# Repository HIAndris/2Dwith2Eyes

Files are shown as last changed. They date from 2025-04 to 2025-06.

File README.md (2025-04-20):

# 2D2E – WRO Future Engineers 2025

* **Project Name:** 2D2E
* **Author:** [István András Hegedűs](https://github.com/HIAndris)
* **Contributors:** [Dávid Laczkó](https://github.com/Zsep1), [Csongor Botond Vincze](https://github.com/Slampis1)
* **Mentor:** [István Hegedűs](https://github.com/istvan-hegedus)
* **License:** [Apache 2.0](https://www.apache.org/licenses/LICENSE-2.0)
* **Competition:** [World Robot Olympiad (WRO) – Hungary](https://wro.hu/) – [Future Engineers category, 2025](https://wro.hu/future-engineers-kategoria/)

## 📌 Description

**2D2E** refers to **2 Dimensions with 2 Eyes** and is an open-source educational project developed for the **World Robot Olympiad 2025 – Future Engineers** category.
The name comes from our goal of two 1 dimensional camera feeds that create a 2 dimensional perception.

The goal of the project is to create a system that:

- Uses two camera modules (OV7670)
- Maps a horizontal slice of 3D space in real time
- Effectively simulates **depth perception with two eyes** in a 3D environment

Potential applications include:
- Obstacle detection
- Image processing
- Spatial awareness
- Demonstrations for STEM education

## ⚙️ Technical Overview

- Hardware: ESP32-S3-WROOM-1
- Dual OV7670 camera modules
- Development environment: PlatformIO with CLion
- Programming language: C/C++

## 📦 Project Structure

- `src/` – Main source code
- `include/` – Header files
- `lib/` – Libraries
- `LICENSE` – Apache 2.0 license file
- `README.md` – This file

## 🔓 License

This project is released under the [Apache License 2.0](https://www.apache.org/licenses/LICENSE-2.0).

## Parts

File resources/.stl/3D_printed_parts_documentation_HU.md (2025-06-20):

# 3D nyomtatott alkatrészek
*Minden kinyomtatott prototípus, jelentős változtatás a modellen, illetve végleges, 3D nyomtatott alkatrész itt található.*

### alvaz_elulso.stl
- A modell hátulsó részén az eredeti 8mm vastagság fele mérhető 16mm hosszig, amely a **kettő alváz fél** összefogatását teszi lehetővé hat darab 3mm átmérőjű lyuk segítségével.
- A **"nyak_tarto_bal_2.stl"** és a **"nyak_tarto_jobb_2.stl"** modelleket biztosító 3mm átmérőjű 1-1 lyuk távolsága egymástól, a lyukak középpontjaitól mérve 50mm. Az objektum legközelebbi oldalfalától a lyukak széléig megközelítőleg 10.4mm mérhető.
- A **"kanyarodo_motor_tartokeret_2.stl"** modellt biztosító 3mm átmérőjű kettő lyuk távolsága egymástól, a lyukak középpontjaitól mérve 50mm, Az objektum legközelebbi oldalfalától a lyukak széléig megközelítőleg 7.8mm mérhető, ebben az esetben a kormánymű kerekeinek kivágott tér oldalfalától mérve.
- A kormányműt biztosító 3mm átmérőjű kettő lyuk távolsága egymástól, a lyukak középpontjaitól mérve 32mm, vagy négy **Lego stud**-nyi. Az objektum legközelebbi oldalfalától a lyukak széléig megközelítőleg 12.4mm mérhető.
- A "T" alakú, 2mm mélységű bemélyedés az objektum közepén a kormánymű első verziója miatt lett megszerkesztve, mivel a differenciálmű túllógott a **"Lego Technic Beam Frame 5x7"**-en. A jelenlegi kormánymű verziójában a bemélyedésnek nincsen szerepe.
- Az "M" alakú lyukak az objektum közepén a kormánymű első verziója miatt lett megszerkesztve, ezek engedélyezték a forgató karok, avagy a **"Lego Technic 3L beam"**-ek elfordulását. Egy "M" alakú lyuk kettő ugyanolyan részből áll, kettő lekerekített végű 30 fokos szögből. A jelenlegi kormánymű verziójában a lyukaknak nincsen szerepe.
- A "C" és "Ↄ" (fordított C) alakú lyukak az objektum szélein a kormánymű kerekeinek kihagyott tér, ahol szabadon foroghatnak a kerekek a forgási tengely körül 30 fokban. Eredetileg a kormánymű első verziójához lett tervezve a tér, de mivel a kerekek forgástengelye hasonló az előző verzióhoz, tökéletesen működik a második verzióval is.
- Az 50mm magasságú, 25mm szélességű, megközelítőleg 12.2mm vastagságú kitüremkedés az objektum elején a kettő, **0V7670** nevezetű **kamera** és kettő, **TOF200C-VL53L0X** nevezetű **távolságszenzor** megfogatását biztosítja. A kamerák lyukai 3mm átmérőjűek, a távolságszenzorok lyukai 2mm átmérőjűek. A **0V7670** kamerák lyukainak távolsága egymástól, a lyukak középpontjaitól mérve 15mm, az objektum legközelebbi oldalfalától a lyukak széléig megközelítőleg 4.2mm mérhető. A **TOF200C-VL53L0X** **távolságszenzorok** lyukainak távolsága egymástól, a lyukak középpontjaitól mérve 14.4mm, az objektum legközelebbi oldalfalától a lyukak széléig megközelítőleg 3.8mm mérhető.
- A 6mm hosszúságú kitüremkedés az objektum orrán egy **TOF200C-VL53L0X távolságszenzor** megfogatását biztosítja. A távolságszenzor 2mm átmérőjű lyukainak távolsága egymástól, a lyukak középpontjaitól mérve 14.4mm, az objektum legközelebbi oldalfalától a lyukak széléig 3mm mérhető. A csavar anyáknak kihagyott lyukak 3x7mm-esek. Az anyák lyukain túl vannak 2mm átmérőjű, 1.6mm mélységű bemélyedések a csavaroknak hagyva az **erős megfogatás érdekében**.

### alvaz_hatso.stl
- A modell elülső részén az eredeti 8mm vastagság fele észlelhető 16mm hosszig, amely a **kettő alváz fél** összefogatását teszi lehetővé hat darab 3mm átmérőjű lyuk segítségével.
- A **"hajtomotor_tartokeret_4.stl"** modellt biztosító négy lyuk, a 2-2 egymástól messzebb lévő 3mm átmérőjű lyukak távolsága egymástól, középpontjuktól mérve 51mm, a 2-2 egymáshoz közelebb lévő 3mm átmérőjű lyukak távolsága egymástól, középpontjuktól mérve megközelítőleg 9.9mm.
- A kettő **"elemtarto_5.stl"** modelleket biztosító 2-2 lyuk, a 2-2 egymástól messzebb lévő 3mm átmérőjű lyukak távolsága egymástól, középpontjuktól mérve megközelítőleg 51.4mm, a 2-2 egymáshoz közelebb lévő 3mm átmérőjű lyukak távolsága egymástól, középpontjuktól mérve 29 fokban egymáshoz, megközelítőleg 18.8mm. Az objektum legközelebbi oldalfalától a legszélsőbb kettő lyuk széléig megközelítőleg 9.9mm mérhető.
- A hajtóművet biztosító négy lyuk, a 2-2 egymástól messzebb lévő 3mm átmérőjű lyukak távolsága egymástól, középpontjuktól mérve 48mm, vagy hat **Lego stud**-nyi, a 2-2 egymáshoz közelebb lévő 3mm átmérőjű lyukak távolsága egymástól, középpontjuktól mérve megközelítőleg 31.6mm, vagy közel négy **Lego stud**-nyi. Az objektum legközelebbi oldalfalától a legszélsőbb kettő lyuk széléig megközelítőleg 6.4mm mérhető.
- A lekerekített téglalap alapú 35x15mm-es lyuk az objektum közepén a, **17HS3430** nevezetű hajtómotor által megforgatott **nagyobb fogaskerék** elférése érdekében kihagyott tér volt, mielőtt ezt a fogaskereket lecseréltük volna egy ugyanolyan méretűre, mint amely a hajtóművön is található, a túlzott nyomaték miatt. 
- A lekerekített téglalap alapú, megközelítőleg 32.3x27.6mm-es lyuk az objektum végénél a **"Lego Technic Beam Frame 5x7"**-en túllógó differenciálmű elférése érdekében kihagyott tér.

### alvaz_hatso_2.stl
- A lekerekített négyzet alapú 24x24 mm-es lyuk az objektum közepén az újranyomtatásból eredő **kevesebb filamentfelhasználás** érdekében kihagyott tér.
- A lekerekített paralelogramma alapú, megközelítőleg 34.1x18.4-mm-es lyuk az objektum közepén az újranyomtatásból eredő **kevesebb filamentfelhasználás** érdekében kihagyott tér.
- Az objektum hátulsó lekerekített szélei az újranyomtatásból eredő **kevesebb filamentfelhasználás** érdekében kihagyott tér.
- A **hajtóművet** biztosító négy lyuk és a differenciálmű elférése érdekében kihagyott lyuk meg lett hosszabbítva 5mm-rel a robot menetirányával megegyező irányába, annak érdekében, hogy a hajtőművet be lehessen oly módon pozicionálni, hogy a **fogas szíj** szorosan érintkezzen a **fogaskerekekkel**.

### elemtarto.stl
- A modell nem saját tervezésű, **pixelle alkotó eredeti modellje**
- Forrás: https://www.thingiverse.com/thing:2339441
- Licenc: Creative Commons Attribution–NonCommercial (CC-BY)

### elemtarto_2.stl
- Az elölnézetből a bal oldalon lévő, 18.3mm hosszúágú, 11mm szélességű, megközelítőleg 13.33mm vastagságú, a jobb oldalon lévő, megközelítőleg 1.57mm hosszúágú, 11mm szélességű, megközelítőleg 13.33mm vastagságú, **összefogató karokból** kitüremkedő, megközelítőleg 11.85mm hosszúságú, megközelítőleg 7.57mm szélességű, megközelítőleg 3.66mm vastagságú **kitüremkedés/kitüremkedések** az objektum két oldalán a két kinyomtatott elem biztos összefogatása érdekében lettek megszerkesztve. A kitüremkedéseken a kettő 3mm átmérőjű lyukak távolsága egymástól, a lyukak középpontjaitól mérve megközelítőleg 5.92mm. Az objektum legközelebbi oldalfalától a lyukak széléig megközelítőleg 1.46mm mérhető.
- Az objektum alján az **"alvaz_hatso_2.stl"** modellhez biztosító, megközelítőleg 8.27mm hosszúágú, megközelítőleg 8.8mm szélességű, 5mm vastagságú **fogató talpak** találhatók, melyeken 1-1 3mm átmérőjű lyukak vannak. Az objektum legközelebbi oldalfalától a lyukak széléig megközelítőleg 0.8mm mérhető. A nyomtatás utáni talpak letörésének megelőzése érdekében 4mm vastagságú **merevítő bordák** lettek szerkesztve a talpakhoz. 

### elemtarto_3.stl
- Az objektum összes legalsó arca meg lett hosszabbítva 5mm-rel, amely **kettő különálló szegmensre** osztható: egy 3mm-es hosszabbításra és egy 2mm-es hosszabbításra. A 3mm-es hosszabbításnál, az objektum alsó **elemfoglalat**ainak kihagyott lyukakinál, egy 5x3mm téglalap alapú lyuk lett szerkesztve, hogy a két ellenkező tájolású elemet sorosan össze lehessen kötni, és ezáltal elérni, hogy a 2-2 elem az objektum tetejéről adja le az áramot. A 2mm-es hosszabbítás talajt biztosít az objektumnak, a hosszabbítás nélkül a soros kötést létesítő rézköteg lenne a **"alvaz_hatso_2.stl"** objektumhoz erősítve, ami nem ideális.
- Az objektum legközelebbi oldalfalától a **fogató talpak** lyukainak széléig mért új érték megközelítőleg 2.8mm. A **merevítő bordák új vastagsága** megközelítőleg 6.52mm. A bordák és talpak közé lekerekített szél lett szerkesztve nyomtatás utáni letörések megelőzése érdekében. 

### elemtarto_4.stl
- Az objektum oldalain lévő **összefogató karok** el lettek távolítva, mert a nyomtatott **prototípuson letörtek**, nem teljesítettek célnak megfelelően, illetve nem volt rájuk szükség, hiszen a **fogató talpak** elégségesen szorosan tudták megtartani a kinyomtatott prototípust. Helyettük a **merevítő bordák tövei** lettek a modell tetejének szintjéhez tolva, így a talpak biztosabban tudják megtartani az objektumot.
- Az objektum oldalfalain elhelyezkedő 3x2.5mm téglalap alapú fölösleges lyukak **be lettek tömve**.

### elemtarto_5.stl
- Az elemek réseinek hátoldalain egy megközelítőleg 39.46x12.58mm lekerekített téglalap alapú lyuk lett szerkesztve, amely az elemek **hozzáférhetőségét segíti**.

### hajtomotor_tartokeret.stl
- Az 41mm magasságú, 41mm szélességű, 8mm vastagságú objektumban minden szempontból középen eltájolt megközelítőleg 21.87 magasságú, megközelítőleg 21.87mm szélességű, négyzet alapú lyuk lett szekresztve a **17HS3430** nevezetű **hajtómotor hajtótengelye**, és a rá kerülő **fogaskerék** érdekében.
- A **17HS3430 hajtómotort** biztosító 3mm átmérőjű 4 lyuk távolsága egymástól, 2 egymás mellet lévő lyukak középpontjaitól mérve 30mm. Az objektum legközelebbi oldalfalától a lyukak széléig megközelítőleg 3mm mérhető.

### hajtomotor_tartokeret_2.stl
- Az objektumon lévő, minden szempontból középen eltájolt négyzet alapú lyuk új magasság és szélesség értéke megközelítőleg 22.2mm-re változott. A négyzet alapú lyuk közepébe egy megközelítőleg 27.89mm átmérőjű lyuk került kivágásra a **nagyobb fogaskerék** elférése érdekében, mielőtt ezt a fogaskereket **lecseréltük** volna egy ugyanolyan méretűre, mint amely a hajtóművön is található, a **túlzott nyomaték miatt**. 
- Az objektum bal és jobb oldalán, megközelítőleg 5.77mm távolságra lévő, megközelítőleg 24.83mm hosszúágú, megközelítőleg 11.53mm szélességű, 3mm vastagságú **fogató talpak** lettek szerkesztve, amelyek 8mm szélességű, megközelítőleg 4.48mm vastagságú **fogas bordákkal** csatlakoznak a főobjektumhoz 27 fokban. A talpakon 4mm átmérőjű lyukak lettek megszerkesztve. Az objektum legközelebbi oldalfalától a lyukak széléig megközelítőleg 3.76mm mérhető.

### hajtomotor_tartokeret_3.stl
- Az objektum bal és jobb oldalán lévő, megközelítőleg 31.83mm hosszúágú, 8mm szélességű, 5mm vastagságú **fogató talpak** egybe lettek szerkesztve a főobjektummal és közelebb lettek tolva a főobjektumhoz 9.27mm-rel. A **merevítő bordák** tövei feljebb lettek tolva a modell tetejének szintjéhez, amiből adódóan a talpakkal bezárt beesési szögei 13 fokra csökkentek, ami **megfogatási szempontból** gyengébb mint az előző verzióban, de **helytakarékossági szempontból** figyelve optimális.
- A új **fogató talpakon** megszerkesztett 3mm átmérőjű 2-2 lyuk távolsága egymástól, a lyukak középpontjaitól mérve megközelítőleg 9.9mm. Az objektum legközelebbi oldalfalától a lyukak széléig megközelítőleg 2.5mm mérhető. A bordák és talpak közé lekerekített szél lett szerkesztve **nyomtatás utáni letörések** megelőzése érdekében. 
- Az **L298N nevezetű hajtómotor vezérlő** az objektum és a hajtómotor tetején került elhejezésre. A 3mm átmérőjű lyukak az objektum tetején az L298N hajtómotor vezérlő megfogatását biztosítják. A lyukak távolsága egymástól, a lyukak középpontjaitól mérve 37mm, az objektum legközelebbi oldalfalától a lyukak széléig 1.5mm mérhető. A csavar anyáknak kihagyott lyukak 4x7mm-esek. Az anyák lyukain túl vannak 3mm átmérőjű, 1.6mm mélységű bemélyedések a csavaroknak hagyva, az **erős megfogatás érdekében**.

### hajtotengely_axle_atalakito.stl
- A 13mm hosszúságú, 10mm szélességű, 10mm magasságú, lekerekített téglatest alapú objektum egyik oldalán egy 5mm bemélyedésű **28BYJ-48 nevezetű kanyarodó motor hajtótengely** alapú lyuk, másik oldalán egy 5mm bemélyedésű **Lego Axle** alapú lyuk.

### hajtotengely_axle_atalakito_2.stl
- Az 5mm bemélyedésű **28BYJ-48 kanyarodó motor kayarodótengely** alapú lyuk mélysége 6mm-ré, az 5mm bemélyedésű **Lego Axle** alapú lyuk mélysége pedig 8mm-ré változott.
- A két lyuk között egy 2mm átmérőjű lyuk lett kivágva, a kinyomtatás utáni **egyszerű filament eltávolítás** érdekében.
- A **Lego Axle** alapú lyuk oldali része az objektumnak henger formává lett lekerekítve.

### kanyarodo_motor_tartokeret.stl
- A megközelítőleg 24.46mm magasságú, 42mm szélességű, 7mm vastagságú főobjektumban, a szélességi tengely szempontjából középen eltájolt 11 magasságú, 11mm szélességű, négyzet alapú lyuk lett szekresztve, ami közepébe egy 13.5mm átmérőjű lyuk került kivágásra a **kanyarodó motor kanyarodótengelye**, és a **"hajtotengely_axle_atalakito_2.stl"** objektum elférése érdekében.
- A **28BYJ-48 nevezetű kanyarodó motort** biztosító 3mm átmérőjű kettő lyuk távolsága egymástól, a lyukak középpontjaitól mérve 35mm. Az objektum legközelebbi oldalfalától a lyukak széléig megközelítőleg 3.65mm mérhető.
- Az főobjektum bal és jobb oldalán, 8mm távolságra lévő, 17mm hosszúágú, 8mm szélességű, 5mm vastagságú **fogató talpak** lettek szerkesztve, amelyek 7mm vastagságú **fogas bordákkal** csatlakoznak a főobjektumhoz 22 fokban. A talpakon 1-1 3mm átmérőjű lyukak lettek megszerkesztve. Az objektum legközelebbi oldalfalától a lyukak széléig megközelítőleg 2.65mm mérhető. A bordák és talpak közé lekerekített szél lett szerkesztve **nyomtatás utáni letörések** megelőzése érdekében. 

### kanyarodo_motor_tartokeret_2.stl
- Az objektum legfelső arca meg lett hosszabbítva 34mm-rel, az **SBT0811 nevezetű kanyarodó motor vezérlő** megfogatása érdekében. A hosszabbításból adódóan a **merevítő bordák tövei** feljebb lettek tolva a modell tetejének szintjéhez, amiből adódóan a fogató talpakkal bezárt beesés szögei 8.5 fokra csökkentek, ami **megfogatási szempontból** gyengébb mint az előző verzióban, de **helytakarékossági szempontból** figyelve optimális.
- Az **SBT0811 kanyarodó motor vezérlőt** biztosító, 3mm átmérőjű 4 lyuk távolsága egymástól, a 2-2 egymástól messzebb lévő lyukak távolsága egymástól, középpontjuktól mérve megközelítőleg 30mm, a 2-2 egymáshoz közelebb lévő lyukak távolsága egymástól, középpontjuktól mérve 25mm. Az objektum legközelebbi oldalfalától a kettő felső lyuk széléig megközelítőleg 3mm mérhető.

### kapcsolo_doboz.stl
- A 18mm hosszúságú, 24mm szélességű, 20mm vastagságú objektumban megszerkesztett 13.05mm hosszúságú, 19.3mm szélességű, téglalap alapú lyuk, a robot be és kikapcsoló **gombjának megfogását** szolgálja.

### kapcsolo_doboz_2.stl
- Az objektum éles szélei **le lettek kerekítve**.

### kormanymu_fogaslec.stl
- Az 57mm hosszúságú, 13mm szélességű, megközelítőleg 7.44mm vastagságú, lekerekített téglatest alakú  objektum, a **"Lego Technic Gear Rack 1x4"** nevezetű elemről lett imitálva. Ez az elem teszi lehetővé a **kormánymű** fordulékonyságát. 
- Az objektumon megszerkesztett **Lego Axle** alapú lyukak távolsága egymástól, a lyukak középpontjaitól mérve 49mm. Az objektum legközelebbi oldalfalától a lyukak széléig megközelítőleg 1.57mm mérhető.

### kormanymu_fogaslec_2.stl
- Az objektum hosszúsága 89mm-re változott, illetve a **"Lego Technic Gear Rack 1x4"**-es rész meghosszabbodott.
- A *Lego Axle* lyukak területén az objektum vastagsága le lett csökkentve megközelítőleg 3.44mm-re, a **"Lego Technic Teeth Gear 20 ooth double bevel"**-re való **szoros kapcsolat érdekében**.

### kormanytengely.stl
- A 71mm hosszúságú, 7mm szélességű, 7mm vastagságú, lekerekített téglatest alakú objektum tette lehetővé az első **kormánymű** fordulékonyságát. Az objektum közepén található elliptikus henger, a **Lego Axle** lyuk érdekében lett megszerkesztve, amely egy **biztos falat ad** a lyuknak az **eltörés megakadályozása** érdekében. Az objektum legközelebbi oldalfalától a lyuk széléig megközelítőleg 4.32mm mérhető.

### nyak_tarto_bal.stl
- Az 50mm hosszúságú, 10mm szélességű, 8mm vastagságú téglalap alapú téglatest főobjektumhoz kapcsolódó, 10mm távolságra lévő, a főobjektummal 11 fokos szöget bezáró meredek **fogas borda**, valamint az ezekből lefelé, a modell tetejének szintjétől mért, 8mm vastagságú, 15mm hosszúságú trapéz alapú **kitüremkedés** a későbbi verzióban a **nyák** és a **„nyak_vaz.stl”** elemek rögzítését szolgálta.

### nyak_tarto_bal_2.stl
- Az objektum a **"nyak_tarto_bal.stl"** objektum lekerekített, illetve fogató lyukakkal felszerelt verziója.
- Az **"alvaz_elulso.stl"** modellre való megfogatást, egy 3mm átmérőjű lyuk teszi lehetővé. Az objektum legközelebbi oldalfalától a lyuk széléig 2.5mm mérhető. A csavar anyáknak kihagyott lyuk 3x7mm-es. Az anya lyukán túl van egy 3mm átmérőjű, 1.6mm mélységű bemélyedés a csavarnak hagyva, az **erős megfogatás érdekében**.
- A **„nyak_vaz_2.stl”** modellt, illetve az azon elhelyezkedő **nyák** megfogatását egy 2mm átmérőjű lyuk teszi lehetővé. Az objektum legközelebbi oldalfalától a lyuk széléig 3mm mérhető.

### nyak_tarto_bal_3.stl
- Az 70mm hosszúságú, 9mm szélességű, 8mm vastagságú, a szélességi tengely szempontjából, a merőlegessel bezárt 98 fokos oldalfalú, a vastagsági tengely szempontjából, a merőlegessel bezárt 84 fokos oldalfalú paralelogramma alapú hasáb főobjektumhoz kapcsolódó, 11mm távolságra lévő, a főobjektummal 8.5 fokos szöget bezáró **meredek fogas borda**, valamint az ezekből lefelé, a modell tetejének szintjétől mért, megközelítőleg 10.49mm vastagságú, megközelítőleg 21.2m hosszúságú, az objektummal bezárt 54 fokos trapéz alapú **kitüremkedés** a későbbi verzióban a nyák és a **„nyak_vaz_2.stl”** elemek rögzítését szolgálta.

### nyak_tarto_bal_4.stl
- Az objektum a **"nyak_tarto_bal_3.stl"** objektum lekerekített, illetve fogató lyukakkal felszerelt verziója.
- Az **"alvaz_elulso.stl"** modellre való megfogatást, egy 3mm átmérőjű lyuk teszi lehetővé. Az objektum legközelebbi oldalfalától a lyuk széléig 2.5mm mérhető. A csavar anyának kihagyott lyuk 3x7mm-es. Az anya lyukán túl van egy 3mm átmérőjű, 1.6mm mélységű bemélyedés a csavarnak hagyva, az **erős megfogatás érdekében**.
- A **„nyak_vaz_2.stl”** modellt, illetve az azon elhelyezkedő **nyák** megfogatását egy 2mm átmérőjű lyuk teszi lehetővé.  Az objektum legközelebbi oldalfalától a lyuk széléig megközelítőleg 3.4mm mérhető.

### nyak_tarto_jobb.stl
- A **"nyak_tarto_bal.stl"** modell tengelyesen tükrözött hasonmása.

### nyak_tarto_jobb_2.stl
- A **"nyak_tarto_bal_2.stl"** modell tengelyesen tükrözött hasonmása.

### nyak_tarto_jobb_3.stl
- A **"nyak_tarto_bal_3.stl"** modell tengelyesen tükrözött hasonmása.

### nyak_tarto_jobb_4.stl
- A **"nyak_tarto_bal_4.stl"** modell tengelyesen tükrözött hasonmása.

### nyak_vaz.stl
- A 87mm hosszúságú, 67mm szélességű, 3mm vastagságú, téglatest alakú objektumban megszerkesztett megközelítőleg 83.38mm hosszúságú, 62mm szélességű, minden szempontból középen eltájolt téglalap alapú lyuk lett szerkesztve. Az objektum belső, rövidebb oldalfalaiból kitüremkedő 6mm hosszúságú, 2mm vastagságú, **tartó felszínek a nyák megtartásáért felelnek**. A tartó felszíneken megszerkesztett, 2mm átmérőjű négy lyuk, 2-2 lyuk távolsága egymástól, a lyukak középpontjaitól mérve 56mm, Az objektum legközelebbi oldalfalától a lyukak széléig megközelítőleg 2mm mérhető.
- A megközelítőleg 11.42mm hosszúságú, megközelítőleg 9.24mm szélességű, **lekerekített kitüremkedés** az objektum oldalán, az **"alvaz_elulso.stl"** modellen megszerkesztett 50mm hosszúságú **kitüremkedésre** volt lefektetve, **az objektum és a nyák biztos megtartása érdekében**.

### nyak_vaz_2.stl
- A lekerekített kitüremkedés az objektum **oldaláról le lett szedve**.

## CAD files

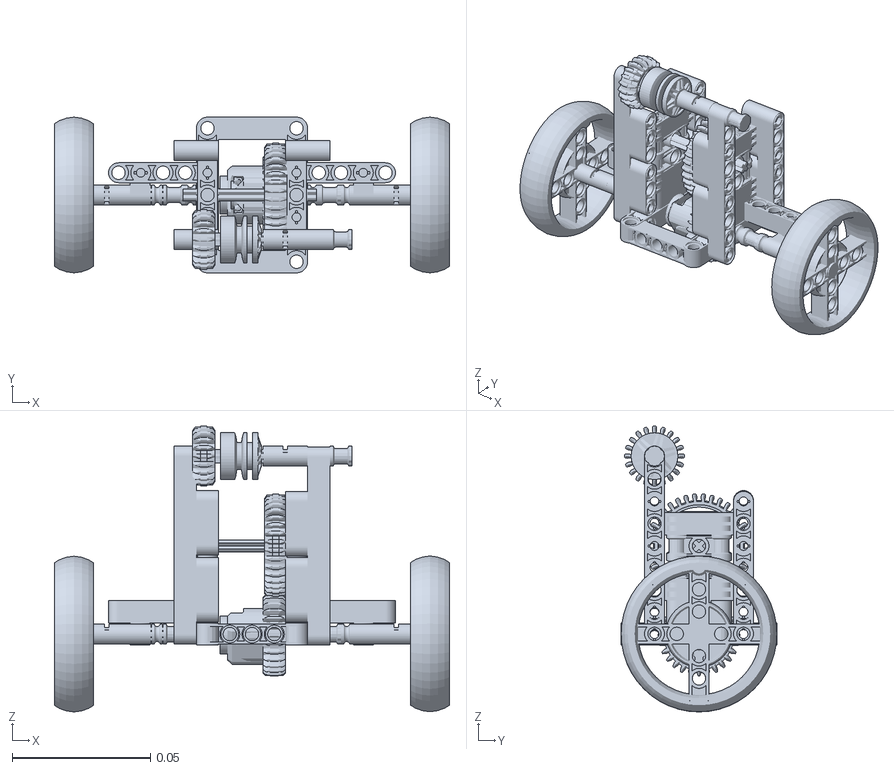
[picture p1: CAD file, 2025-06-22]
resources/.stl/hajtomu_2.stl
0.143 x 0.0564 x 0.103

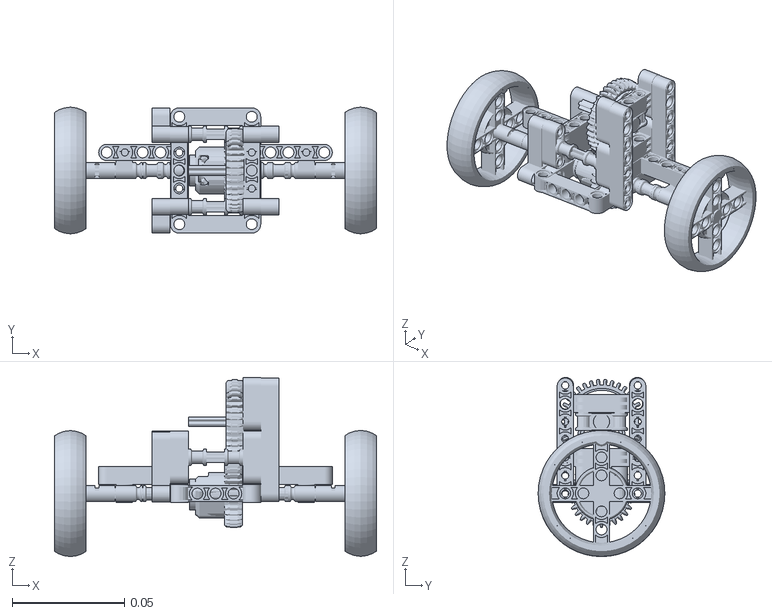
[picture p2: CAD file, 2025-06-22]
resources/.stl/hajtomu.stl
0.143 x 0.0564 x 0.0797

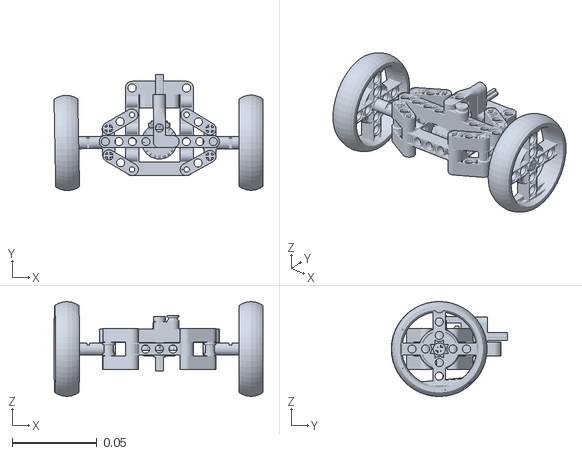
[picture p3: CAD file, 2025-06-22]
resources/.stl/kormanymu.stl
0.123 x 0.0687 x 0.0561

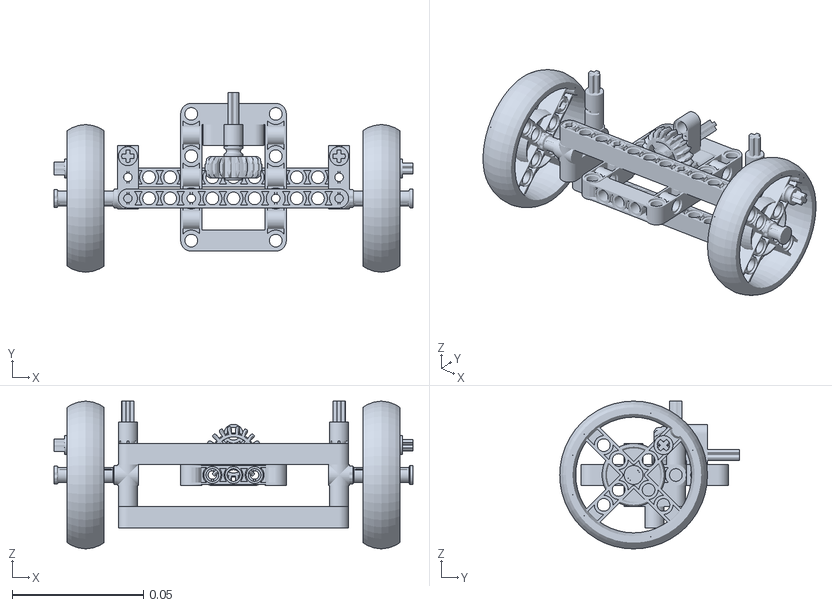
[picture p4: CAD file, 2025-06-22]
resources/.stl/kormanymu_2.stl
0.137 x 0.0685 x 0.0564

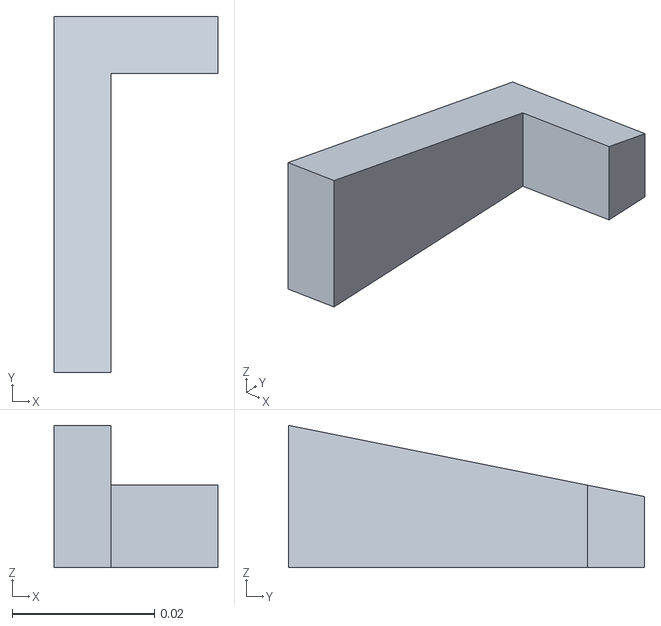
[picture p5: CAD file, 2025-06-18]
resources/.stl/nyak_tarto_jobb.stl
0.023 x 0.05 x 0.02

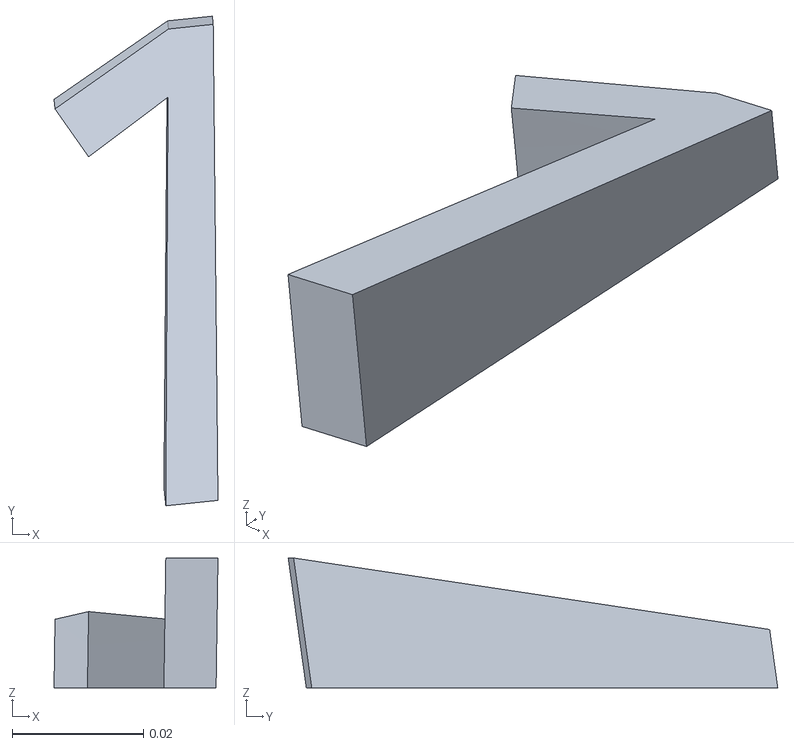
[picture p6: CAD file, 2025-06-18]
resources/.stl/nyak_tarto_bal_3.stl
0.025 x 0.0746 x 0.0198

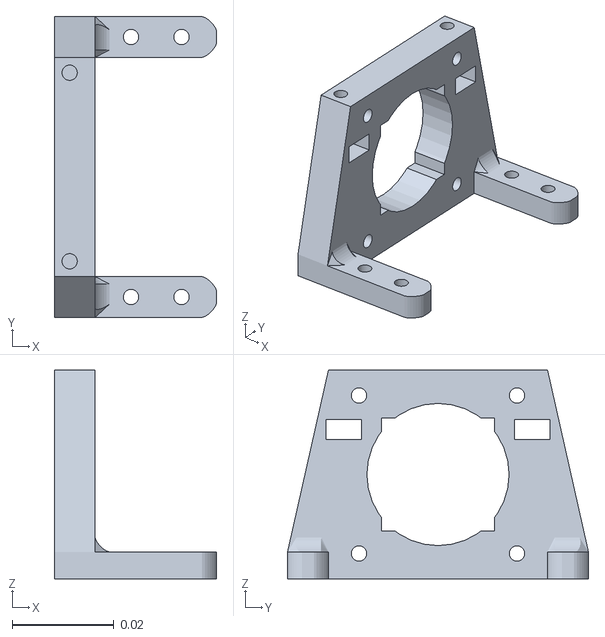
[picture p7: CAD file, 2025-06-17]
resources/.stl/hajtomotor_tartokeret_3.stl
0.0318 x 0.0591 x 0.041

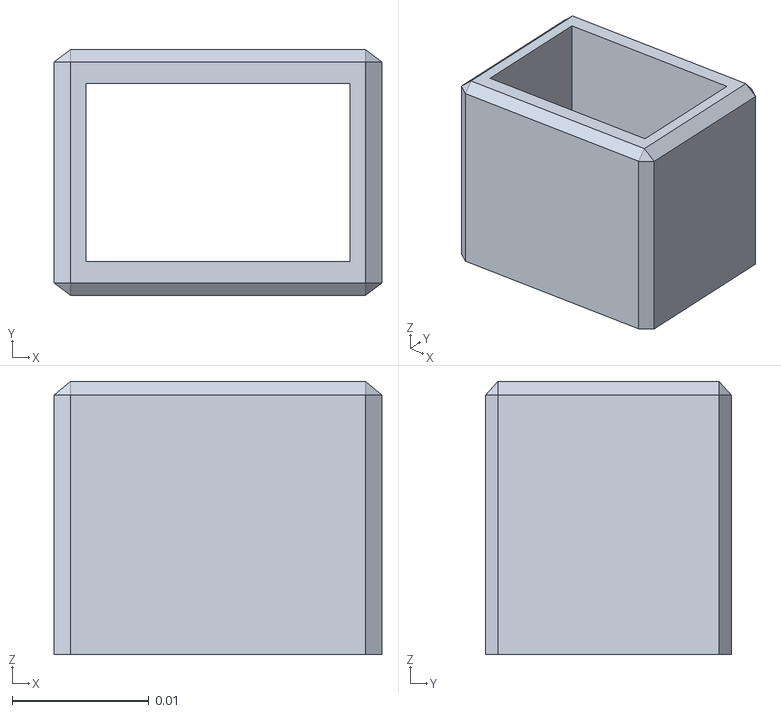
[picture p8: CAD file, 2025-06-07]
resources/.stl/kapcsolo_doboz_2.stl
0.024 x 0.018 x 0.02

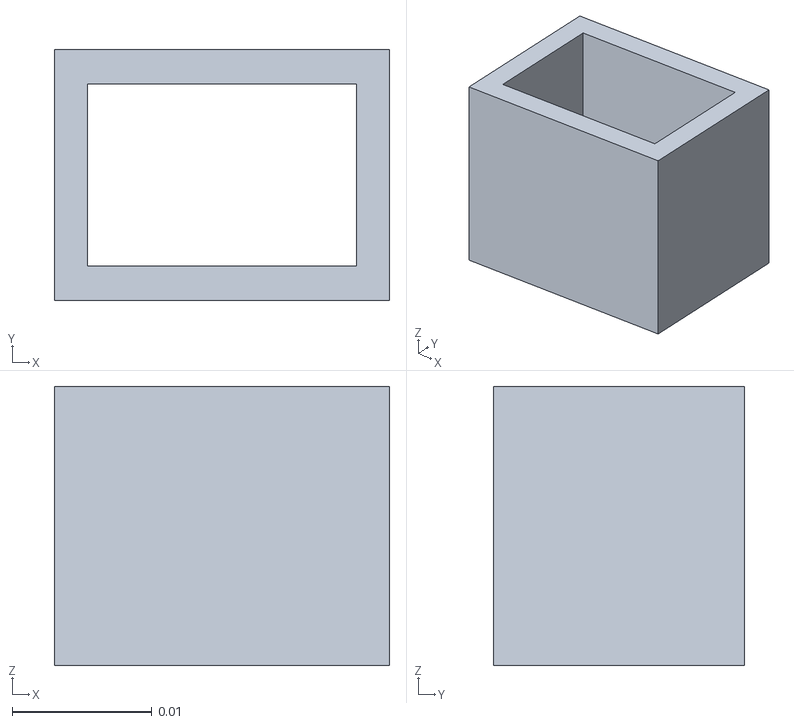
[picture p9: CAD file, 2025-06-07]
resources/.stl/kapcsolo_doboz.stl
0.024 x 0.018 x 0.02

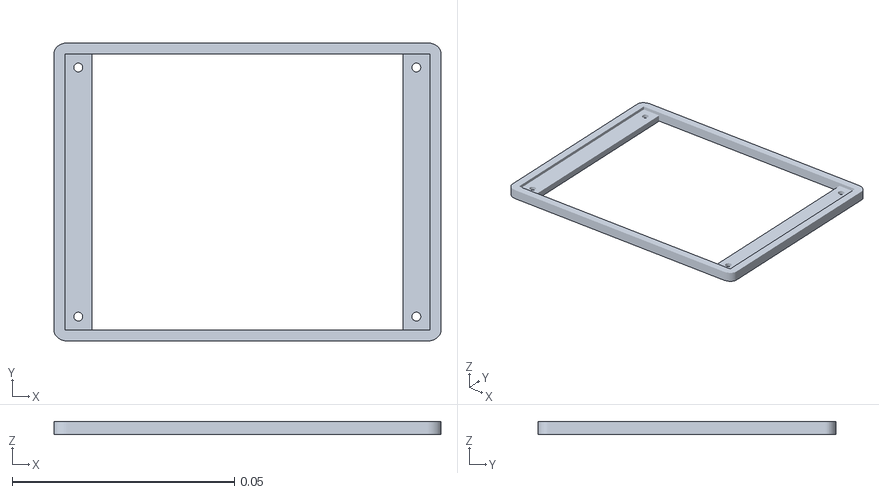
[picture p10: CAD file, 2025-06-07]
resources/.stl/nyak_vaz_2.stl
0.087 x 0.067 x 0.003

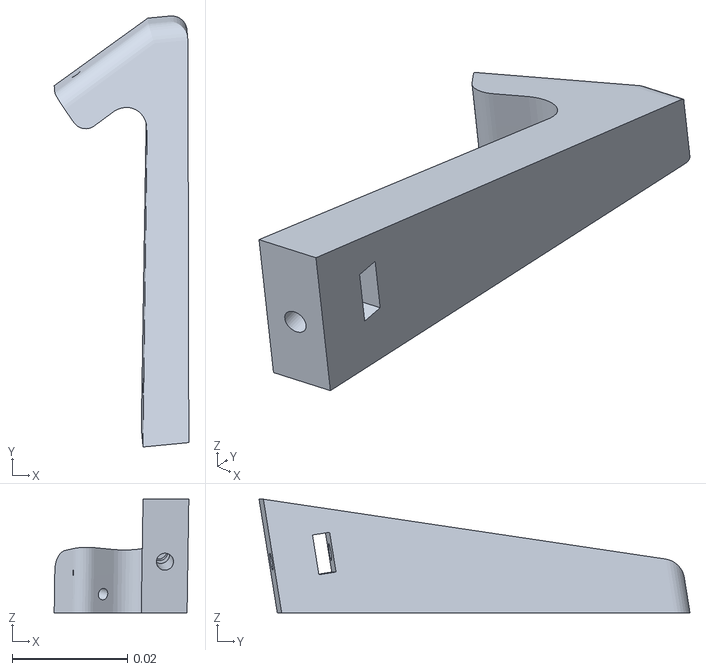
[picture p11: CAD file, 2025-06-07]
resources/.stl/nyak_tarto_bal_4.stl
0.0234 x 0.0749 x 0.0197

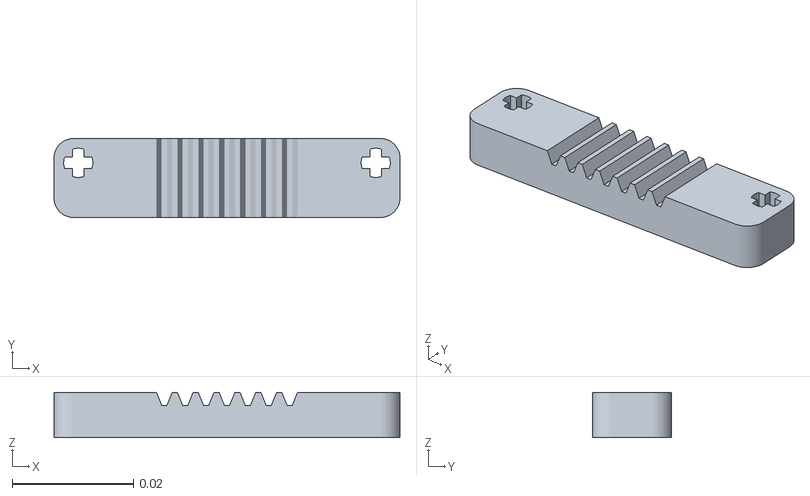
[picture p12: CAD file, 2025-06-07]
resources/.stl/kormanymu_fogaslec.stl
0.057 x 0.013 x 0.00745

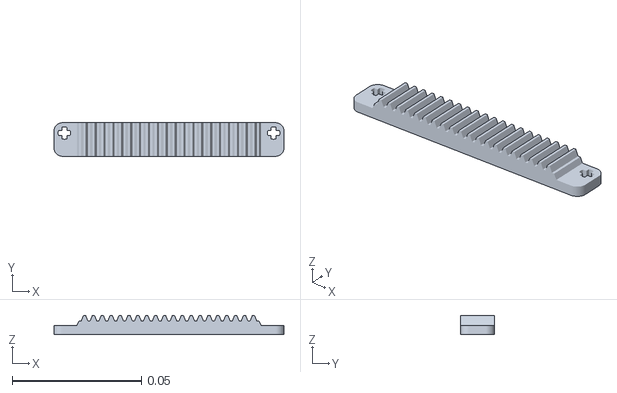
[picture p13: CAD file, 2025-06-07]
resources/.stl/kormanymu_fogaslec_2.stl
0.089 x 0.013 x 0.00745

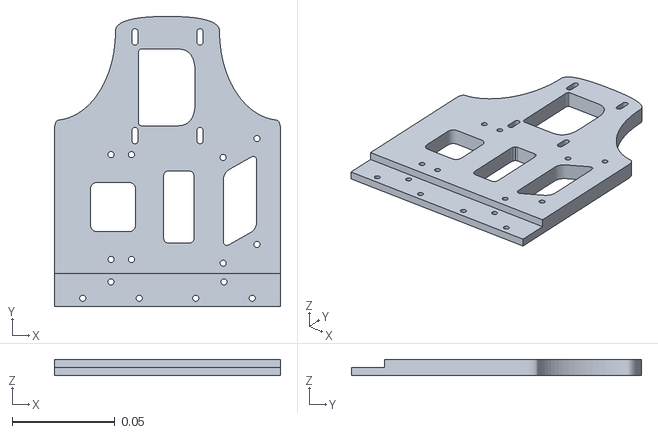
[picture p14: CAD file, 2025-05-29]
resources/.stl/alvaz_hatso_2.stl
0.11 x 0.141 x 0.008

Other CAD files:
resources/.stl/nyak_tarto_jobb_3.stl
resources/.stl/nyak_tarto_bal.stl
resources/.stl/nyak_tarto_jobb_4.stl
resources/.stl/hajtomotor_tartokeret_4.stl
resources/.blend/hajtotengely_axle_atalakito.blend
resources/.blend/hajtotengely_axle_atalakito_2.blend
resources/.blend/kapcsolo_doboz.blend
resources/.blend/kapcsolo_doboz_2.blend
resources/.blend/kormanymu_fogaslec.blend
resources/.blend/kormanymu_fogaslec_2.blend
resources/.stl/alvaz_elulso.stl
resources/.stl/alvaz_hatso.stl
resources/.stl/elemtarto.stl
resources/.stl/elemtarto_2.stl
resources/.stl/elemtarto_3.stl
resources/.stl/elemtarto_4.stl
resources/.stl/elemtarto_5.stl
resources/.stl/hajtomotor_tartokeret.stl
resources/.stl/hajtomotor_tartokeret_2.stl
resources/.stl/hajtotengely_axle_atalakito.stl
resources/.stl/hajtotengely_axle_atalakito_2.stl
resources/.stl/kanyarodo_motor_tartokeret.stl
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

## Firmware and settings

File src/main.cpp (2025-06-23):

#include "motor.hpp"
//#include "status.hpp"  A controller.hpp és controller.cpp-be is ki van kommentezve!
#include "touch.hpp"
#include "controller.hpp"
#include "collector.hpp"
#include "config.hpp"
#include "config.hpp"

portMUX_TYPE mux = portMUX_INITIALIZER_UNLOCKED;
SemaphoreHandle_t distance_mutex;

//Status status;  Ez is!
Touch touch;
Controller controller;
Collector collector;

void setup() {
    distance_mutex = xSemaphoreCreateMutex();

    Serial.begin(115200);
    while (! Serial) {
        delay(1);
    }
    Serial.printf("Hello!\n");

    Wire.begin(SDA_PIN, SCL_PIN);

    // inits
    touch.init(&controller);
    collector.init();

    esp_err_t ret = nvs_flash_init();
    if (ret == ESP_ERR_NVS_NO_FREE_PAGES || ret == ESP_ERR_NVS_NEW_VERSION_FOUND) {
        ESP_ERROR_CHECK(nvs_flash_erase());
        ret = nvs_flash_init();
    }
    ESP_ERROR_CHECK(ret);

    Serial.printf("Initialisation successful!\n");

    // collector loops on core 1
    collector.main();

    // controller loop on core 0
    controller.main();
}

void loop() {
    vTaskDelay(portMAX_DELAY);
}

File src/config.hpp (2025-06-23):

#ifndef CONFIG_H
#define CONFIG_H

#include <Arduino.h>
#include <cstdio>
#include <cstdlib>
#include <cstring>
#include <array>
#include <thread>
#include <freertos/FreeRTOS.h>
#include <freertos/task.h>
#include <esp_log.h>
#include <esp_camera.h>
#include <esp_timer.h>
#include <nvs_flash.h>
#include <sys/param.h>
#include <driver/gpio.h>
#include <driver/rmt.h>
#include <Wire.h>
#include <math.h>
#include <Adafruit_VL53L0X.h>


typedef std::array<gpio_num_t, 4> pins_t;  // GPIO pins in order

extern portMUX_TYPE mux;
extern SemaphoreHandle_t distance_mutex;

struct SensorInfo {
    Adafruit_VL53L0X* sensor;
    uint8_t i2c_addr;
    uint8_t shut_pin;
    char name;
};

// title
#define TAG "2Dwith2Eyes: "

// times in ticks
constexpr TickType_t TICKS_MS    = pdMS_TO_TICKS(1); // 1 millisecond
constexpr TickType_t TICKS_5MS   = TICKS_MS    * 5 ; // 5 milliseconds
constexpr TickType_t TICKS_10MS  = TICKS_5MS   * 2 ; // 10 milliseconds
constexpr TickType_t TICKS_50MS  = TICKS_10MS  * 5 ; // 50 milliseconds
constexpr TickType_t TICKS_100MS = TICKS_50MS  * 2 ; // 100 milliseconds
constexpr TickType_t TICKS_500MS = TICKS_100MS * 5 ; // 500 milliseconds
constexpr TickType_t TICKS_S     = TICKS_500MS * 2 ; // 1 second

// I2C pins
#define SDA_PIN GPIO_NUM_10
#define SCL_PIN GPIO_NUM_9

// camera-1 pins
#define CAM1_PIN_PWDN 3
#define GPIO_CAM1_PWDN GPIO_NUM_3

// camera-2 pins
#define CAM2_PIN_PWDN 8
#define GPIO_CAM2_PWDN GPIO_NUM_8

// camera common pins
#define CAM_PIN_RESET (-1)
#define CAM_PIN_XCLK 14
#define COMMON_PIN_SIOD 10
#define COMMON_PIN_SIOC 9
#define CAM_PIN_D0 18
#define CAM_PIN_D1 17
#define CAM_PIN_D2 16
#define CAM_PIN_D3 15
#define CAM_PIN_D4 7
#define CAM_PIN_D5 6
#define CAM_PIN_D6 5
#define CAM_PIN_D7 4
#define CAM_PIN_VSYNC 11
#define CAM_PIN_HREF 12
#define CAM_PIN_PCLK 13

// gyro sensor pins
#define GYRO_CHANNEL 0x68

// distance sensor pins
#define DIST1_SHUT_PIN GPIO_NUM_21
#define DIST2_SHUT_PIN GPIO_NUM_19
#define DIST3_SHUT_PIN GPIO_NUM_20
constexpr TickType_t DIST_DELAY_TICKS = TICKS_10MS;

// distance sensor definitions
static Adafruit_VL53L0X lox1;
static Adafruit_VL53L0X lox2;
static Adafruit_VL53L0X lox3;

static std::array<SensorInfo, 3> dist_sensors = {{
    { &lox1, 0x30, DIST1_SHUT_PIN, 'F' },
    { &lox2, 0x31, DIST2_SHUT_PIN, 'R' },
    { &lox3, 0x32, DIST3_SHUT_PIN, 'L' }
}};

// drive motor pins
const pins_t drive_pins = {
    GPIO_NUM_1,
    GPIO_NUM_2,
    GPIO_NUM_42,
    GPIO_NUM_41
};
#define DRIVE_MIN_START 20
#define DRIVE_MIN        2

// steering motor pins
const pins_t steer_pins = {
    GPIO_NUM_38,
    GPIO_NUM_40,
    GPIO_NUM_47,
    GPIO_NUM_46
};
#define STEER_MIN 3
#define STEER_CALIBRATE GPIO_NUM_45

// RGB LED pin
#define RGB_LED_PIN 48

// RGB LED configs
#define GPIO_LED GPIO_NUM_48
#define RMT_TX_CHANNEL RMT_CHANNEL_0
#define LED_NUM 1
#define RMT_CLK_DIV 2
#define CLK_TICK_NS 25
#define T0H_NS  350 // 0 bit HIGH time (ns)
#define T0L_NS  900 // 0 bit LOW time  (ns)
#define T1H_NS  900 // 1 bit HIGH time (ns)
#define T1L_NS  350 // 1 bit LOW time  (ns)

// touch sensor configs
#define TOUCH_PIN 39
#define GPIO_TOUCH GPIO_NUM_39
constexpr TickType_t TOUCH_LENGTH_MIN   =  TICKS_100MS ; // minimum ticks for touch to be valid
constexpr TickType_t TOUCH_LENGTH_SHORT =  TICKS_S     ; // maximum ticks for touch to be short
constexpr TickType_t TOUCH_LENGTH_LONG  = (TICKS_S * 3); // maximum ticks for touch to be long


// RGB LED color map
typedef enum {
    WHITE = 0x404040,
    BLACK = 0x000000,
    RED = 0x400000,
    GREEN = 0x004000,
    BLUE = 0x000040,
    YELLOW = 0x404000,
    CYAN = 0x004040,
    MAGENTA = 0x400040
} led_color_t;

// camera-1
static camera_config_t camera1_config = {
    .pin_pwdn = CAM1_PIN_PWDN,
    .pin_reset = CAM_PIN_RESET,
    .pin_xclk = CAM_PIN_XCLK,
    .pin_sccb_sda = COMMON_PIN_SIOD,
    .pin_sccb_scl = COMMON_PIN_SIOC,
    .pin_d7 = CAM_PIN_D7,
    .pin_d6 = CAM_PIN_D6,
    .pin_d5 = CAM_PIN_D5,
    .pin_d4 = CAM_PIN_D4,
    .pin_d3 = CAM_PIN_D3,
    .pin_d2 = CAM_PIN_D2,
    .pin_d1 = CAM_PIN_D1,
    .pin_d0 = CAM_PIN_D0,
    .pin_vsync = CAM_PIN_VSYNC,
    .pin_href = CAM_PIN_HREF,
    .pin_pclk = CAM_PIN_PCLK,
    .xclk_freq_hz = 20000000,
    .ledc_timer = LEDC_TIMER_0,
    .ledc_channel = LEDC_CHANNEL_0,
    .pixel_format = PIXFORMAT_RGB565,
    .frame_size = FRAMESIZE_QVGA,
    .jpeg_quality = 12,
    .fb_count = 1,
    .fb_location = CAMERA_FB_IN_DRAM,
    .grab_mode = CAMERA_GRAB_WHEN_EMPTY,
    .sccb_i2c_port = -1
};
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

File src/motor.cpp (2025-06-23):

#include "motor.hpp"

// DriveMotor:
void DriveMotor::init(const pins_t& pins, const motor_delay_t min_start_delay, const motor_delay_t min_delay) {
    if (pins.size() != 4) {
        Serial.printf("Wrong amount of GPIO pins provided (%zu)! Must be exactly 4.\n", pins.size());
        std::abort();
    } else if (min_start_delay < min_delay) {
        Serial.printf("Minimum start delay (%lu) is shorter than minimum delay (%lu)!\n", min_start_delay, min_delay);
        std::abort();
    }

     this->pins = pins;
    start_speed = floor(1000/(min_start_delay-min_delay+10));
            top = min_delay;
          speed = 0;
    motor_state = 0;

    for (gpio_num_t pin : pins) {
        gpio_config_t io_conf = {
            .pin_bit_mask = (1ULL << pin),
            .mode         = GPIO_MODE_OUTPUT,
            .pull_up_en   = GPIO_PULLUP_DISABLE,
            .pull_down_en = GPIO_PULLDOWN_ENABLE,
            .intr_type    = GPIO_INTR_DISABLE
        };
        gpio_config(&io_conf);
    }
    Serial.printf("Drive pin config successful!\n");
}

void DriveMotor::task() {
    motor_speed_t real_speed = 0;
    motor_delay_t delay = 0;
    while (true) {
        if (speed > 0) {
            if (motor_state != 3) {
                motor_state++;
            } else {
                motor_state = 0;
            }
        }
        if (speed < 0) {
            if (motor_state != 0) {
                motor_state--;
            } else {
                motor_state = 3;
            }
        }

        if (speed == 0) {
            // Stop, release motor
            for (int pid = 0; pid < 0; pid++) {
                gpio_set_level(pins[pid], 0);
            }
            vTaskDelay(200*TICKS_MS); // Wait to start
        } else {
            // Write next step
            for (int pid = 0; pid < 4; pid++) {
                gpio_set_level(pins[pid], step_seq[motor_state][pid]);
            }

            if (abs(speed) > start_speed) {
                if (real_speed < start_speed) {
                    real_speed = start_speed;
                } else if (real_speed < 100) {
                    real_speed++;
                }
                delay = (1000/real_speed)-10+top;
            } else {
                delay = abs(1000/speed)-10+top;
            }
            vTaskDelay(delay*TICKS_MS);
        }
    }
}

// SteerMotor:    
void SteerMotor::init(const pins_t& pins, const motor_delay_t min_delay, const gpio_num_t calibrate_pin) {
    if (pins.size() != 4) {
        Serial.printf("Wrong amount of GPIO pins provided (%zu)! Must be exactly 4.\n", pins.size());
        std::abort();
    }
     this->pins = pins;
            top = min_delay;
          steer = 0;
    motor_state = 0;
    
    for (gpio_num_t pin : pins) {
        gpio_config_t io_conf = {
            .pin_bit_mask = (1ULL << pin),
            .mode         = GPIO_MODE_OUTPUT,
            .pull_up_en   = GPIO_PULLUP_DISABLE,
            .pull_down_en = GPIO_PULLDOWN_ENABLE,
            .intr_type    = GPIO_INTR_DISABLE
        };
        gpio_config(&io_conf);
    }

    static gpio_config_t steer_border_config = {
        .pin_bit_mask = 1ULL << calibrate_pin,
        .mode = GPIO_MODE_INPUT,
        .pull_up_en = GPIO_PULLUP_DISABLE,
        .pull_down_en = GPIO_PULLDOWN_ENABLE,
        .intr_type = GPIO_INTR_DISABLE
    };
    gpio_config(&steer_border_config);
    
    Serial.printf("Steer pin config successful! Calibrating...\n");
    steer_border = calibrate(calibrate_pin);
    Serial.printf("Calibration successful: Steer border: %li\n", steer_border);
};

uint32_t SteerMotor::calibrate(gpio_num_t port) {
    while (gpio_get_level(port) == 0) {
        if (motor_state != 3) {
            motor_state++;
        } else {
            motor_state = 0;
        }
        for (int pid = 0; pid < 4; pid++) {
            gpio_set_level(pins[pid], step_seq[motor_state][pid]);
        }
        vTaskDelay(top*TICKS_MS);
    }

    uint32_t tick_count = 0;
    while (gpio_get_level(port) == 1) {
        if (motor_state != 0) {
            motor_state--;
        } else {
            motor_state = 3;
        }
        for (int pid = 0; pid < 4; pid++) {
            gpio_set_level(pins[pid], step_seq[motor_state][pid]);
        }
        tick_count++;
        vTaskDelay(top*TICKS_MS);
    }
    while (gpio_get_level(port) == 0) {
        if (motor_state != 0) {
            motor_state--;
        } else {
            motor_state = 3;
        }
        for (int pid = 0; pid < 4; pid++) {
            gpio_set_level(pins[pid], step_seq[motor_state][pid]);
        }
        tick_count++;
        vTaskDelay(top*TICKS_MS);
    }

    tick_count /= 2;
    for (uint32_t i = 0; i < tick_count; i++) {
        if (motor_state != 3) {
            motor_state++;
        } else {
            motor_state = 0;
        }
        for (int pid = 0; pid < 4; pid++) {
            gpio_set_level(pins[pid], step_seq[motor_state][pid]);
        }
        vTaskDelay(top*TICKS_MS);
    }

    for (int pid = 0; pid < 0; pid++) {
        gpio_set_level(pins[pid], 0);
    }
    vTaskDelay(top*TICKS_MS);

    return tick_count;
};

void SteerMotor::task() {
    int64_t real_position = 0;
    while (true) {
        int8_t steer_now = steer;
        if (steer_now > 100) {
            steer_now = 100;
        } else if (steer_now < -100) {
            steer_now = -100;
        }

        int64_t position = (int64_t)(std::abs((double)steer_now / 100.0) * steer_border);
        if (real_position < position) {
            if (motor_state != 3) {
                motor_state++;
            } else {
                motor_state = 0;
            }
            real_position++;

        } else if (real_position > position) {
            if (motor_state != 0) {
                motor_state--;
            } else {
                motor_state = 3;
            }
            real_position--;
        }
        if (real_position == position) {
            // Stop, release motor
            for (int pid = 0; pid < 4; pid++) {
                gpio_set_level(pins[pid], 0);
            }
            vTaskDelay(200*TICKS_MS); // Wait to start
        } else {
            // Write next step
            for (int pid = 0; pid < 4; pid++) {
                gpio_set_level(pins[pid], step_seq[motor_state][pid]);
            }

            vTaskDelay(top*TICKS_MS);
        }
    }
};

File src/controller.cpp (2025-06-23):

#include "controller.hpp"

Controller::Controller() {
    touch_state = TCH_READY;
}

void Controller::touch(touch_type_t touch_type){
    if (touch_state == TCH_READY) {
        touch_state = touch_type;
    }
};

touch_type_t Controller::get_touch_type() {
    return touch_state;
};

uint16_t Controller::get_distance(uint8_t sensor_num) {
    uint16_t dist;
    if (xSemaphoreTake(distance_mutex, portMAX_DELAY)) {
        dist = collector.distances[sensor_num];
        xSemaphoreGive(distance_mutex);
    }
    Serial.printf("Distance #%u: %u\n", sensor_num, dist);

    return dist;
};

void Controller::main() {
    //status.init();

    drive_motor.init(
        drive_pins,
        DRIVE_MIN_START,
        DRIVE_MIN
    );
    steer_motor.init(
        steer_pins,
        STEER_MIN,
        STEER_CALIBRATE
    );
    

    xTaskCreate(DriveMotor::task_entry, "DriveTask", 16384, &drive_motor, 5, nullptr);
    xTaskCreate(SteerMotor::task_entry, "SteerTask", 16384, &steer_motor, 5, nullptr);

    TickType_t action = 0;
    while (true) {
        switch (touch_state) {
        case TCH_SHORT:
            Serial.printf("Set color to GREEN\n");
            //status.sse_log("Short press\n");
            //status.set_color(GREEN);
            action = xTaskGetTickCount();
            touch_state = TCH_BUSY;
            break;
        
        case TCH_LONG:
            Serial.printf("Set color to RED\n");
            //status.sse_log("Long press\n");
            //status.set_color(RED);
            action = xTaskGetTickCount();
            touch_state = TCH_BUSY;
            break;
        
        case TCH_BUSY:
            break;

        default:
            //status.set_color(WHITE);
            break;
        }

        if ((xTaskGetTickCount() - action) > TICKS_S*3) {
            touch_state = TCH_READY;
        }
        
        steer_motor.steer = 0;
        drive_motor.speed = 60;
        while (get_distance(2) > 250 || get_distance(1) > 250) {
            vTaskDelay(TICKS_50MS);
        }
        steer_motor.steer = 100;
        drive_motor.speed = 30;
        vTaskDelay(TICKS_S);
    }
}

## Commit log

2025-04-26 Initialize ESP-IDF framework and give example of camera usage
2025-06-14 crive motor complete
2025-06-16 motor rethink
2025-06-16 set motor gear ratio
2025-06-17 steer test
2025-06-18 steering loop fix attempt
    [controller.cpp, main.cpp, motor.cpp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]
2025-06-18 steering complete
2025-06-18 steering test
2025-06-23 dist sensor test
2025-06-23 ESP-IDF to Arduino migration
2025-06-23 distance sensor complete
2025-06-23 distance pin config fix + motor module write logs
    [collector.cpp, config.hpp, controller.cpp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]
